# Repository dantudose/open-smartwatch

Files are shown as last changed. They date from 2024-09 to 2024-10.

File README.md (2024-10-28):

# Open-Smartwatch
An open hardware and software smartwatch.

## Main Hardware Diagram

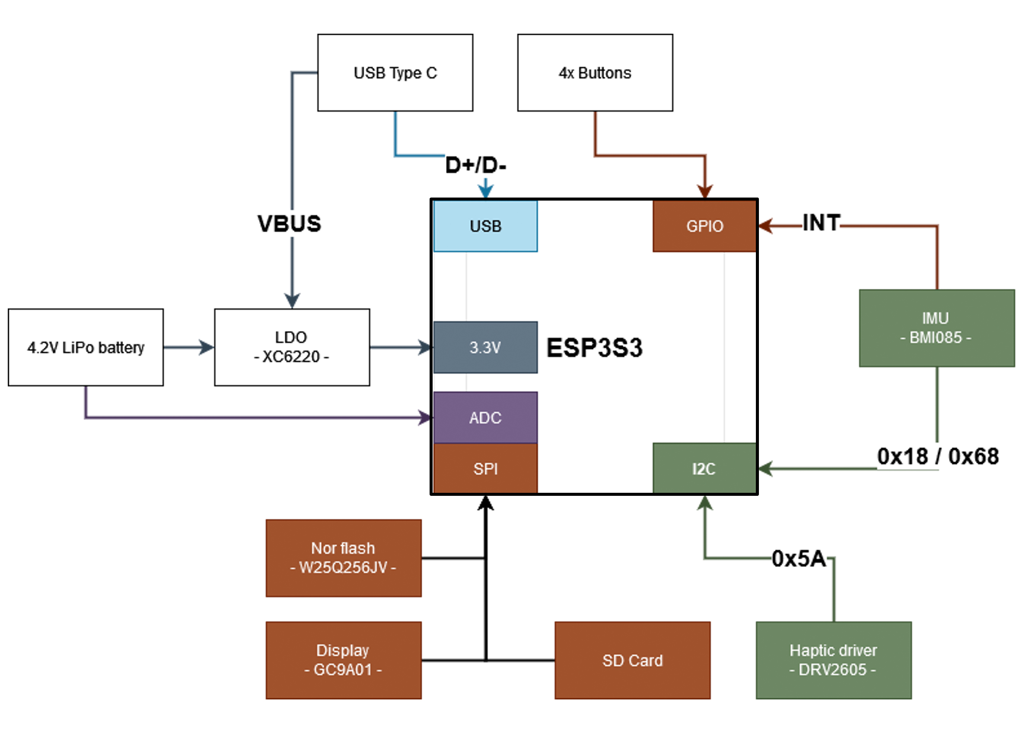
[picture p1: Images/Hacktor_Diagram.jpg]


This is a open-hardware wearable based on the ESP32 microcontroller. It is fully Arduino-compatible and it comes with the following features:
* ESP32-S3 Mini module (240MHz, WiFI, BLE, 512kB SRAM and 4MB Flash)
* GC9A01 1.28 inch color LCD, 240 x 240 pixels
* BMI085 6-axis inertial sensor (accelerometer and gyroscope)
* W25Q256JVEIQ 32MB external SPI Flash
* DRV2605 haptic driver
* SPI card reader
* 200mAh LiPo battery
* USB-C connector

## Repository Contents

* **/Hardware** - Eagle design files (.brd, .sch)
* **/Images** - Board images
* **/Mechanical** - Mechanical files for the case (.stl)
  
### Button Layout

 <div style='float:left'>
<table>
<thead>
  <tr>
    <th>Button</th>
    <th>ESP32 Pin</th>
  </tr></thead>
  <tbody>
  <tr>
    <td>UP</td>
    <td>IO11</td>
  </tr>
  <tr>
    <td>DOWN</td>
    <td>IO26</td>
  </tr>
  <tr>
    <td>BOOT</td>
    <td>IO0</td>
  </tr>
  <tr>
    <td>RESET</td>
    <td>EN</td>
  </tr>
  </tbody>
</table>
 </div>
<div style='float:right'>
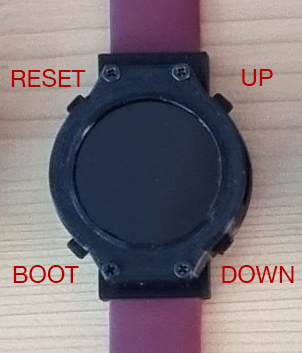
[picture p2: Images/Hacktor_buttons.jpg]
   
  </div>

## Mechanical Dimensions

The watch has the overall dimensions of 43.5 x 48 x 18mm and supports standard 20mm straps.

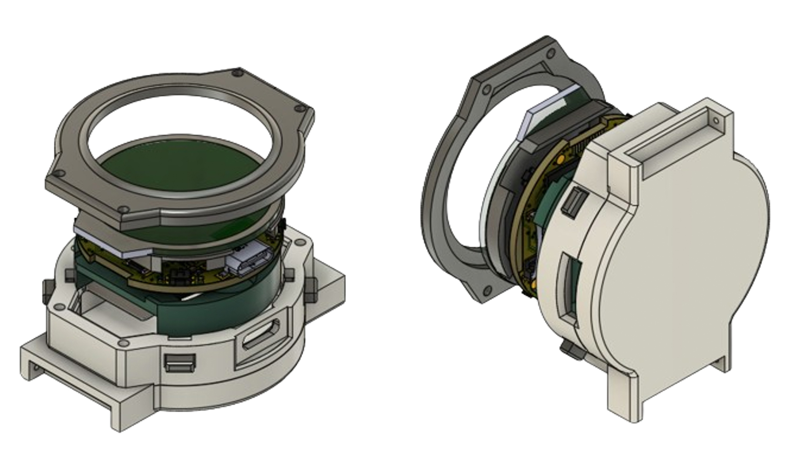
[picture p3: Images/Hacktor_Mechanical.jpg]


## PCB Design

Two-layer PCB design.

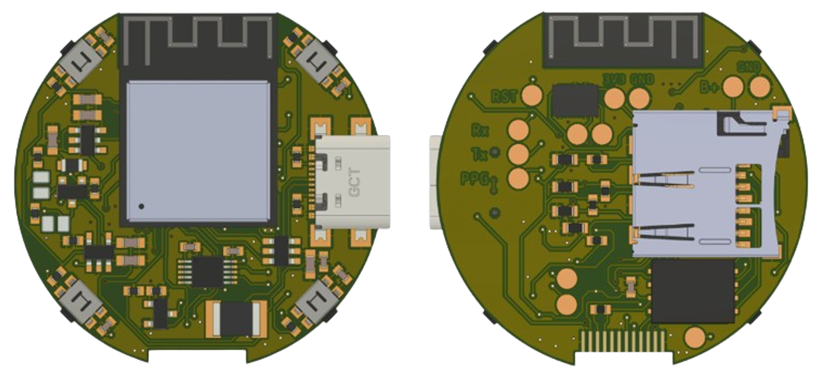
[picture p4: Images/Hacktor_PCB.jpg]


## License Information

This product is _**open source**_! 

Please review the LICENSE file for license information.

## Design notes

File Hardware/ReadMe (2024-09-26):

Eagle CAD files for the schematic and board.

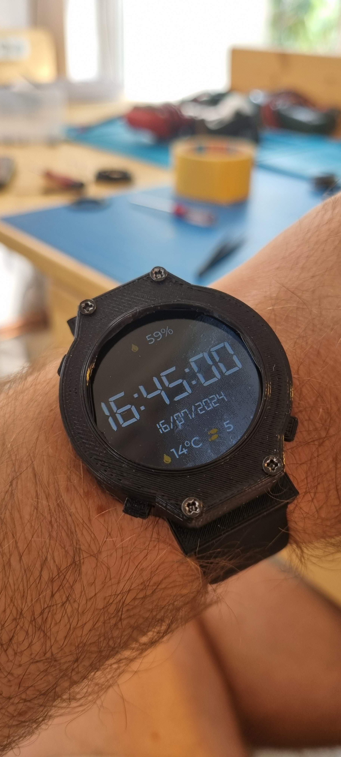
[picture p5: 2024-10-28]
Images/Hacktor_Watch.jpg

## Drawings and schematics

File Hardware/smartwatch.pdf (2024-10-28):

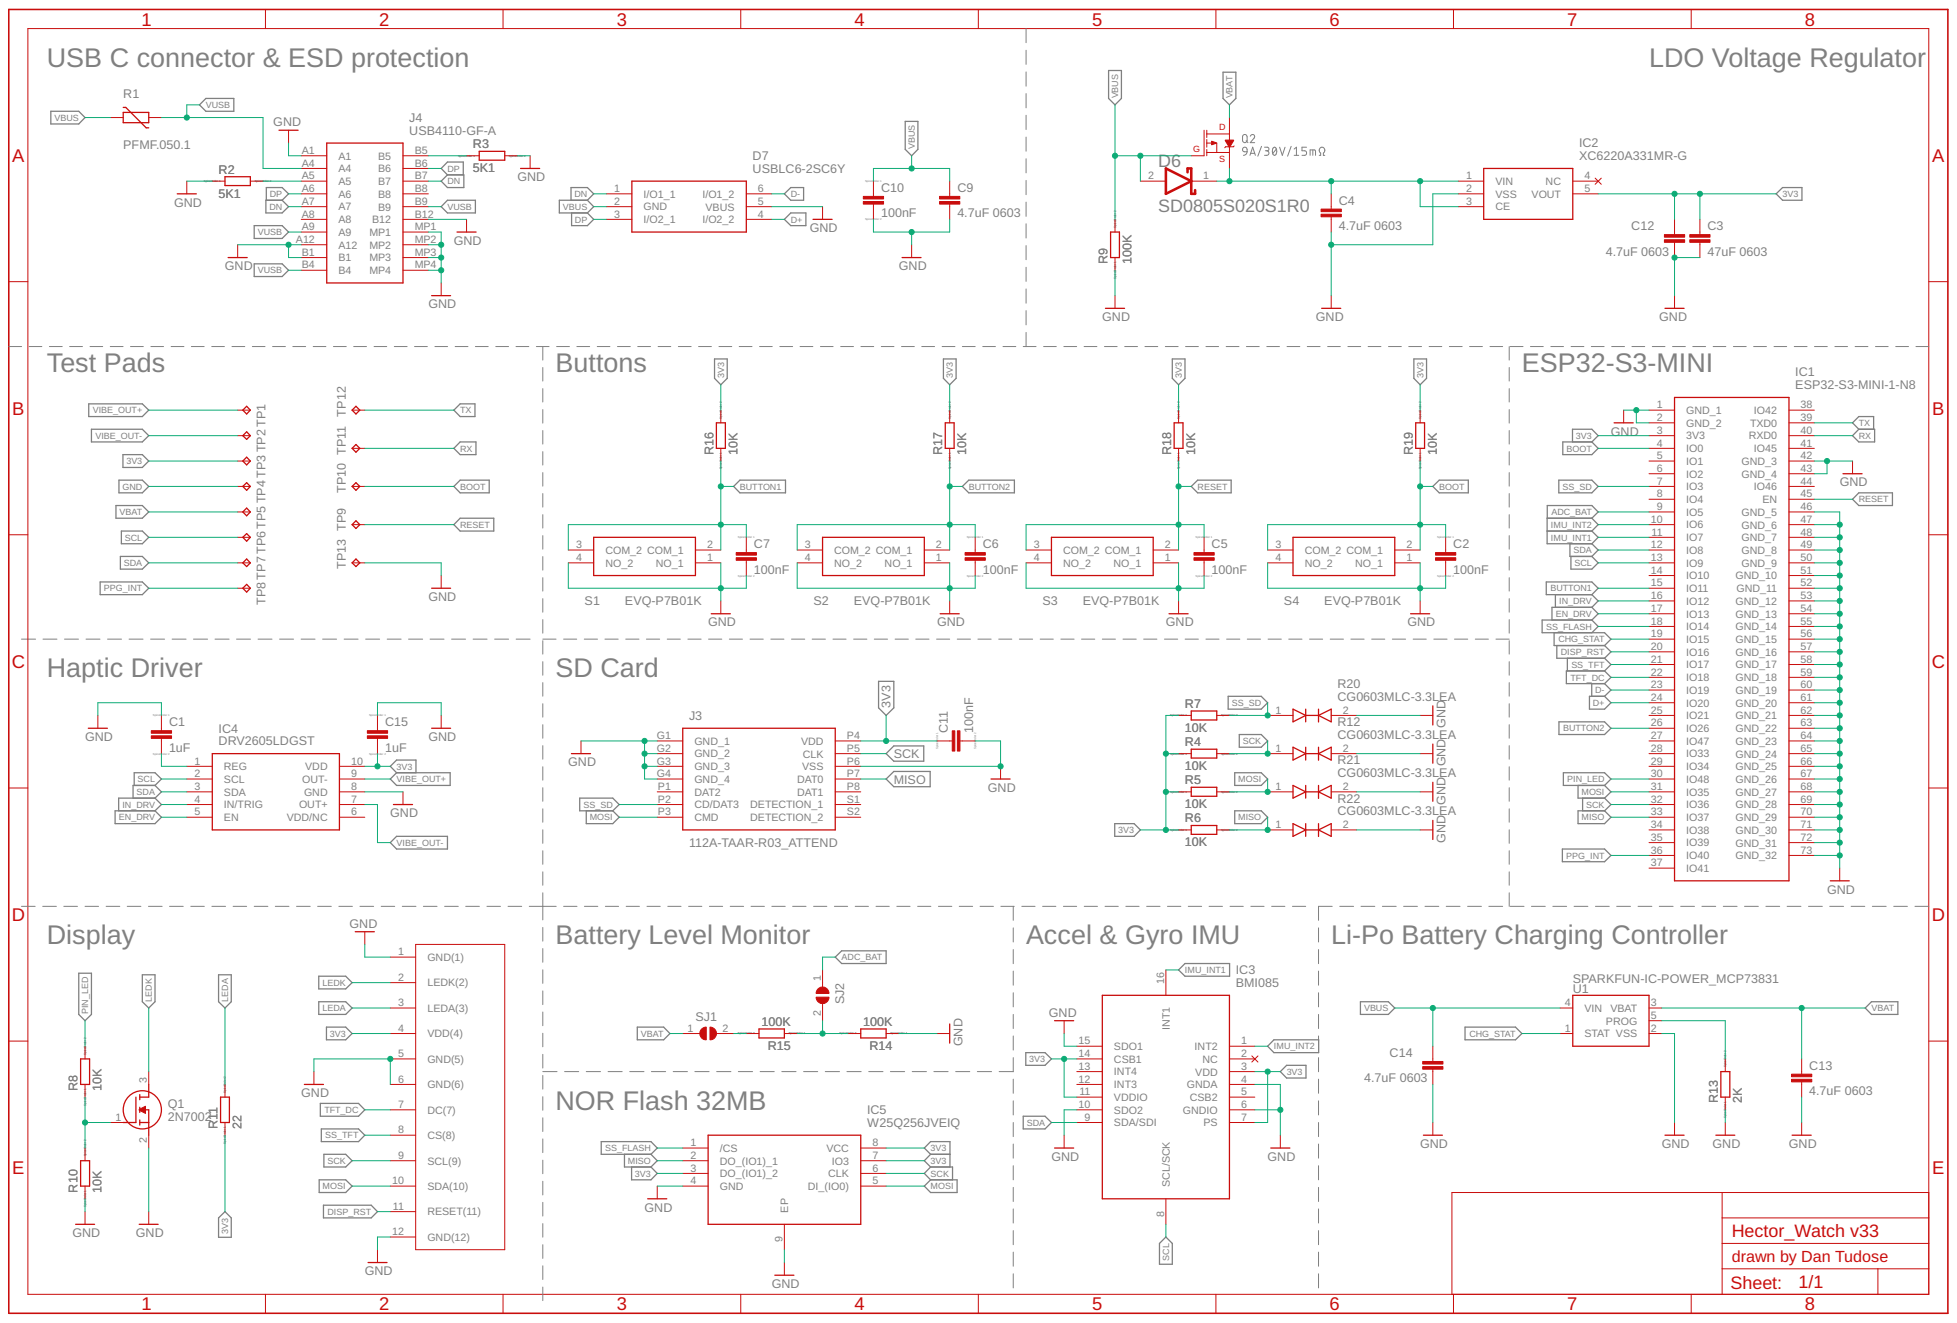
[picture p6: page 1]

USB C connector & ESD protection

SpiceOrder 1 SpiceOrder 2

GND GND

SpiceOrder 1 SpiceOrder 2 SpiceOrder 1 SpiceOrder 2 SpiceOrder 1

SpiceOrder 1 SpiceOrder 2 SpiceOrder 1 SpiceOrder 2

4 GNDIO 5 GNDA 6

drawn by Dan Tudose Hector_Watch v33

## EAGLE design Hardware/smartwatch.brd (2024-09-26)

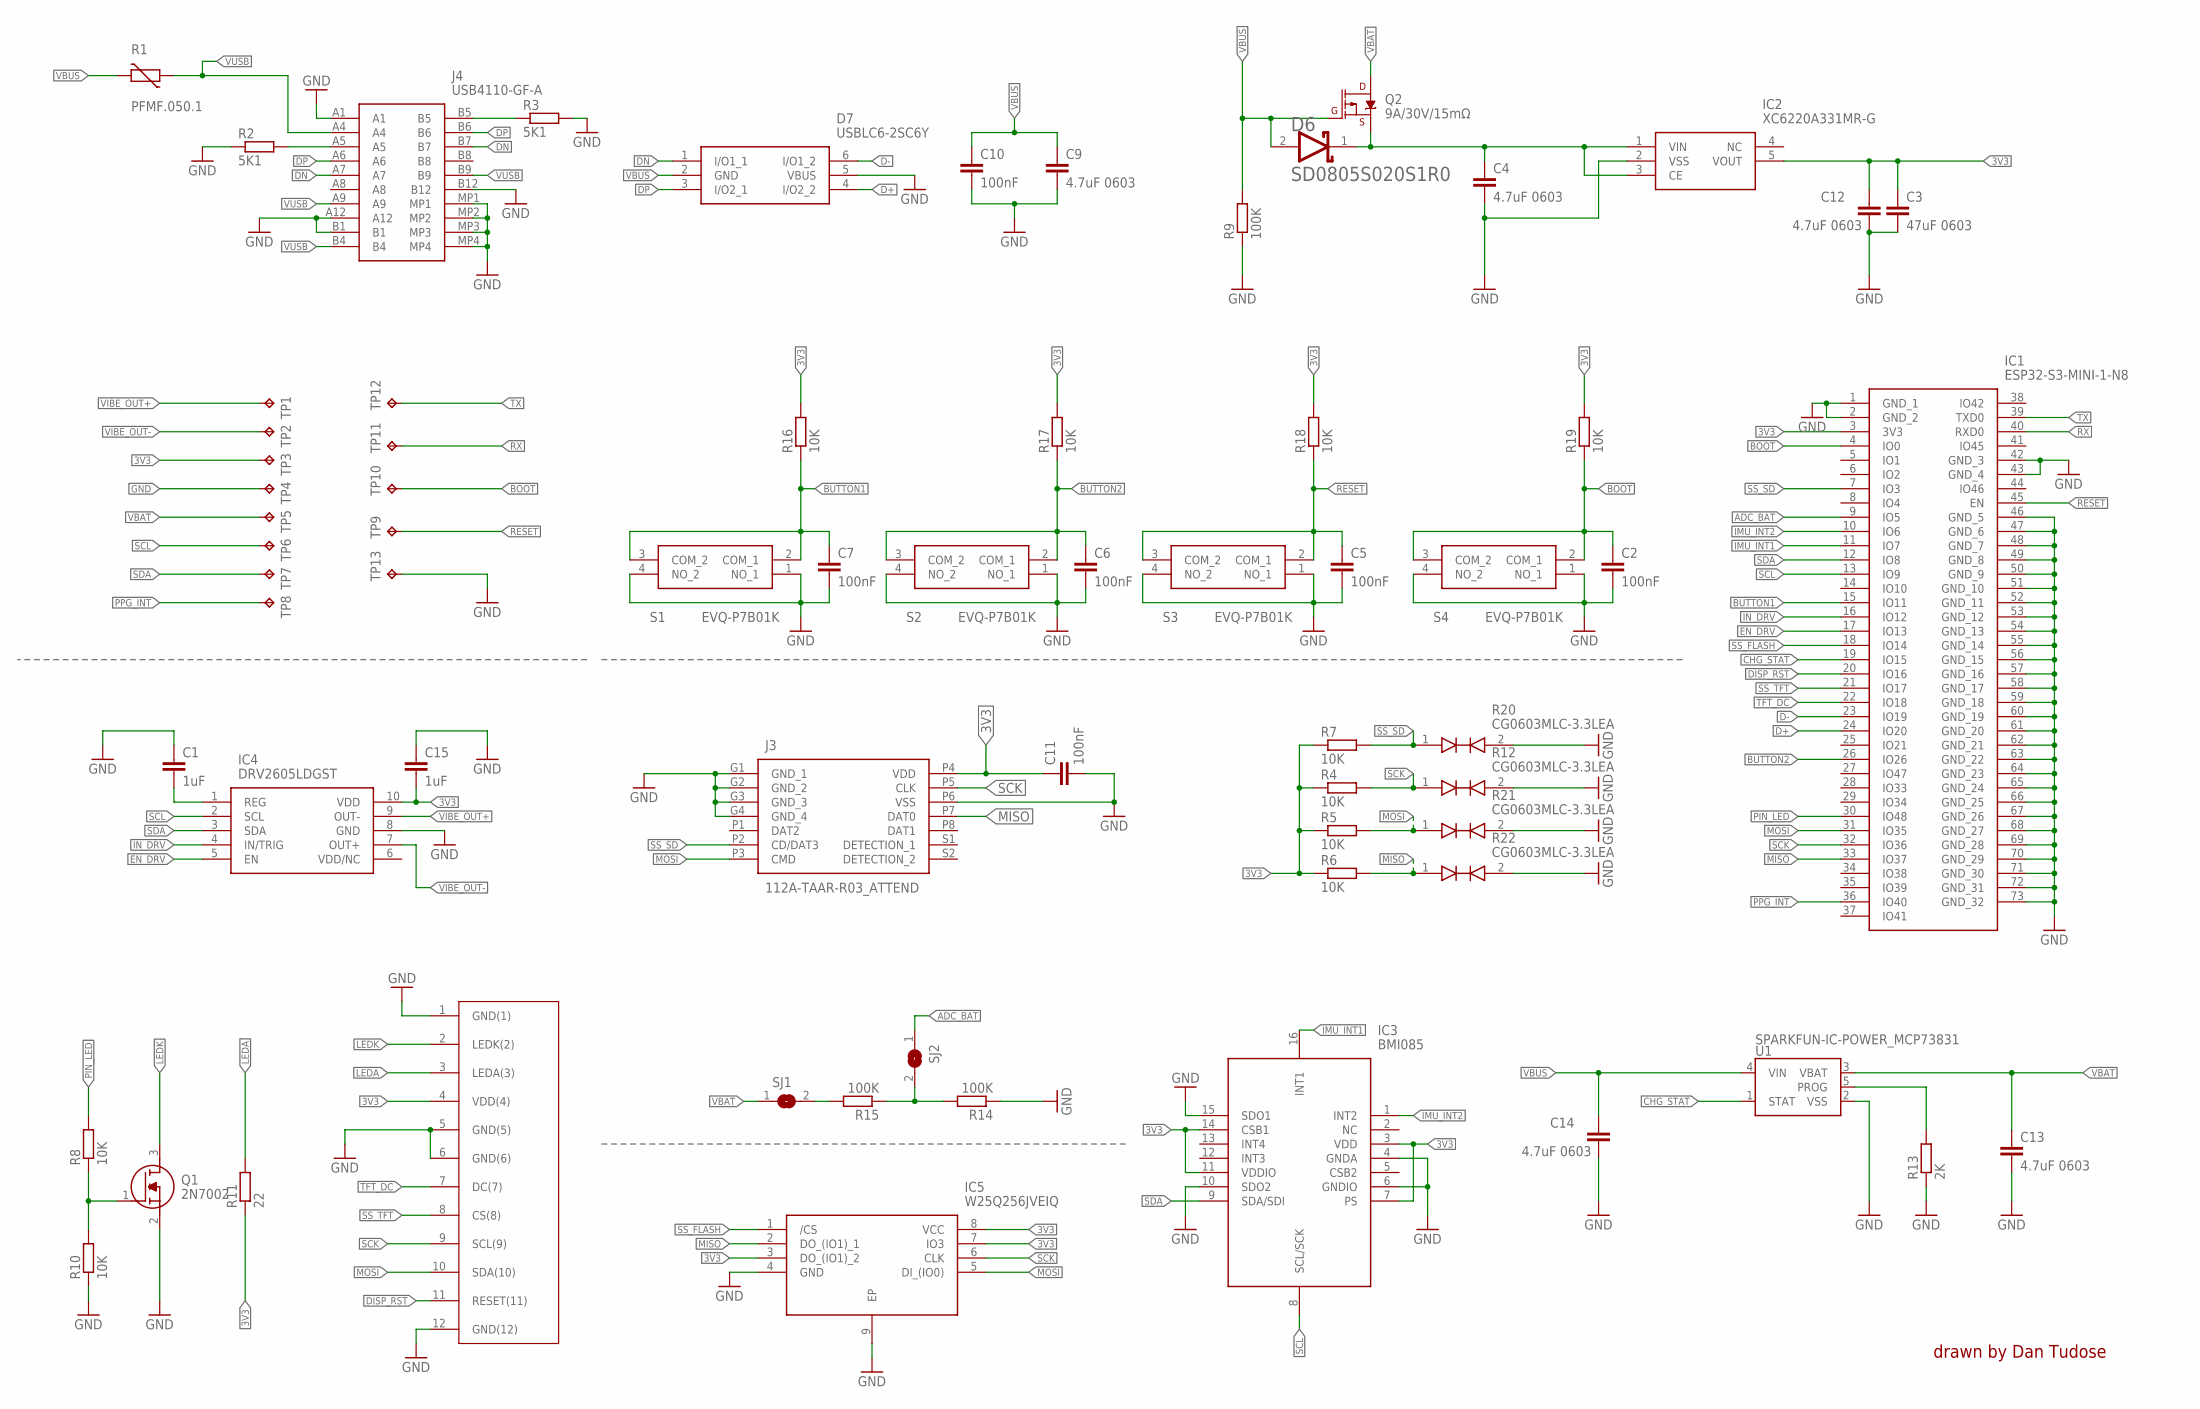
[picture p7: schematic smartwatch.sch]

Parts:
C1, C15: 1uF; EAGLE-LTSPICE_C0402
C2, C5, C6, C7, C10, C11: 100nF; EAGLE-LTSPICE_C0402
C3: 47uF 0603; RCL_C0603
C4, C9, C12, C13, C14: 4.7uF 0603; RCL_C0603
CON1: LCD_FPC
D6: AVX---SD0805S020S1R0_AVX_SD0805S020S1R0AVX_SD0805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; AVX---SD0805S020S1R0_AVX_SD0805S020S1R0_0
D7: USBLC6-2SC6Y; SOT95P280X145-6N
IC1: ESP32-S3-MINI-1-N8; ESP32S3MINI1N8
IC2: XC6220A331MR-G; SOT95P280X120-5N
IC3: BMI085
IC4: DRV2605LDGST; SOP50P490X110-10N
IC5: W25Q256JVEIQ; SON127P800X600X80-9N
J3: 112A-TAAR-R03_ATTEND; 112ATAARR03ATTEND
J4: USB4110-GF-A; USB4110GFA
Q1: 2N7002; SOT96P240X120-3N
Q2: 9A/30V/15mΩ; SPARKFUN-DISCRETESEMI_SOT23-3
R1: PFMF.050.1; VARISTOR_CT/CN1812
R2, R3: 5K1; EAGLE-LTSPICE_R0402
R4, R5, R6, R7, R8, R10, R16, R17, R18, R19: 10K; EAGLE-LTSPICE_R0402
R9, R14, R15: 100K; EAGLE-LTSPICE_R0402
R11: 22; EAGLE-LTSPICE_R0402
R12, R20, R21, R22: CG0603MLC-3.3LEA; DIONC1608X61N
R13: 2K; EAGLE-LTSPICE_R0402
S1, S2, S3, S4: EVQ-P7B01K; EVQP7B01K
SJ1, SJ2: SJ
TP1, TP2, TP3, TP4, TP5, TP6, TP7, TP8, TP9, TP10, TP11, TP12, TP13: TPTP20R; TP20R
U1: SPARKFUN-IC-POWER_MCP73831; SPARKFUN-IC-POWER_SOT23-5

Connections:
3V3: C3.1, C11.1, C12.1, C15.2, CON1.4 (VDD(4)), IC1.3 (3V3), IC2.5 (VOUT), IC3.3 (VDD), IC3.7 (PS), IC3.11 (VDDIO), IC3.14 (CSB1), IC4.10 (VDD), IC5.3 (DO_(IO1)_2), IC5.7 (IO3), IC5.8 (VCC), J3.P4 (VDD), R4.1, R5.1, R6.1, R7.1, R11.1, R16.2, R17.2, R18.2, R19.2, TP3.TP
ADC_BAT: IC1.9 (IO5), SJ2.1
BOOT: C2.1, IC1.4 (IO0), R19.1, S4.2 (COM_1), S4.3 (COM_2), TP10.TP
BUTTON1: C7.1, IC1.15 (IO11), R16.1, S1.2 (COM_1), S1.3 (COM_2)
BUTTON2: C6.1, IC1.26 (IO26), R17.1, S2.2 (COM_1), S2.3 (COM_2)
CHG_STAT: IC1.19 (IO15), U1.1 (STAT)
D+: D7.4 (I/O2_2), IC1.24 (IO20)
D-: D7.6 (I/O1_2), IC1.23 (IO19)
DISP_RST: CON1.11 (RESET(11)), IC1.20 (IO16)
DN: D7.1 (I/O1_1), J4.A7, J4.B7
DP: D7.3 (I/O2_1), J4.A6, J4.B6
EN_DRV: IC1.17 (IO13), IC4.5 (EN)
GND: C1.1, C2.2, C3.2, C4.2, C5.2, C6.2, C7.2, C9.2, C10.2, C11.2, C12.2, C13.2, C14.2, C15.1, CON1.1 (GND(1)), CON1.5 (GND(5)), CON1.6 (GND(6)), CON1.12 (GND(12)), D7.5 (VBUS), IC1.1 (GND_1), IC1.2 (GND_2), IC1.42 (GND_3), IC1.43 (GND_4), IC1.46 (GND_5), IC1.47 (GND_6), IC1.48 (GND_7), IC1.49 (GND_8), IC1.50 (GND_9), IC1.51 (GND_10), IC1.52 (GND_11), IC1.53 (GND_12), IC1.54 (GND_13), IC1.55 (GND_14), IC1.56 (GND_15), IC1.57 (GND_16), IC1.58 (GND_17), IC1.59 (GND_18), IC1.60 (GND_19), IC1.61 (GND_20), IC1.62 (GND_21), IC1.63 (GND_22), IC1.64 (GND_23), IC1.65 (GND_24), IC1.66 (GND_25), IC1.67 (GND_26), IC1.68 (GND_27), IC1.69 (GND_28), IC1.70 (GND_29), IC1.71 (GND_30), IC1.72 (GND_31), IC1.73 (GND_32), IC2.2 (VSS), IC3.4 (GNDA), IC3.6 (GNDIO), IC3.10 (SDO2), IC3.15 (SDO1), IC4.8 (GND), IC5.4 (GND), IC5.9 (EP), J3.G1 (GND_1), J3.G2 (GND_2), J3.G3 (GND_3), J3.G4 (GND_4), J3.P6 (VSS), J4.A1, J4.A12, J4.B1, J4.B12, J4.MP1, J4.MP2, J4.MP3, J4.MP4, Q1.2 (S), R2.1, R3.2, R9.1, R10.1, R12.2, R13.1, R14.1, R20.2, R21.2, R22.2, S1.1 (NO_1), S1.4 (NO_2), S2.1 (NO_1), S2.4 (NO_2), S3.1 (NO_1), S3.4 (NO_2), S4.1 (NO_1), S4.4 (NO_2), TP4.TP, TP13.TP, U1.2 (VSS)
IMU_INT1: IC1.11 (IO7), IC3.16 (INT1)
IMU_INT2: IC1.10 (IO6), IC3.1 (INT2)
IN_DRV: IC1.16 (IO12), IC4.4 (IN/TRIG)
LEDA: CON1.3 (LEDA(3)), R11.2
LEDK: CON1.2 (LEDK(2)), Q1.3 (D)
MISO: IC1.33 (IO37), IC5.2 (DO_(IO1)_1), J3.P7 (DAT0), R6.2, R22.1
MOSI: CON1.10 (SDA(10)), IC1.31 (IO35), IC5.5 (DI_(IO0)), J3.P3 (CMD), R5.2, R21.1
unnamed: C1.2, IC4.1 (REG)
unnamed: C4.1, D6.1 (CATHODE), IC2.1 (VIN), IC2.3 (CE), Q2.2 (S)
unnamed: J4.A5, R2.2
unnamed: R13.2, U1.5 (PROG)
unnamed: J4.B5, R3.1
unnamed: Q1.1 (G), R8.1, R10.2
unnamed: R14.2, R15.1, SJ2.2
unnamed: R15.2, SJ1.2
PIN_LED: IC1.30 (IO48), R8.2
PPG_INT: IC1.36 (IO40), TP8.TP
RESET: C5.1, IC1.45 (EN), R18.1, S3.2 (COM_1), S3.3 (COM_2), TP9.TP
RX: IC1.40 (RXD0), TP11.TP
SCK: CON1.9 (SCL(9)), IC1.32 (IO36), IC5.6 (CLK), J3.P5 (CLK), R4.2, R12.1
SCL: IC1.13 (IO9), IC3.8 (SCL/SCK), IC4.2 (SCL), TP6.TP
SDA: IC1.12 (IO8), IC3.9 (SDA/SDI), IC4.3 (SDA), TP7.TP
SS_FLASH: IC1.18 (IO14), IC5.1 (/CS)
SS_SD: IC1.7 (IO3), J3.P2 (CD/DAT3), R7.2, R20.1
SS_TFT: CON1.8 (CS(8)), IC1.21 (IO17)
TFT_DC: CON1.7 (DC(7)), IC1.22 (IO18)
TX: IC1.39 (TXD0), TP12.TP
VBAT: C13.1, Q2.3 (D), SJ1.1, TP5.TP, U1.3 (VBAT)
VBUS: C9.1, C10.1, C14.1, D6.2 (ANODE), D7.2 (GND), Q2.1 (G), R1.2, R9.2, U1.4 (VIN)
VIBE_OUT+: IC4.9 (OUT-), TP1.TP
VIBE_OUT-: IC4.7 (OUT+), TP2.TP
VUSB: J4.A4, J4.A9, J4.B4, J4.B9, R1.1

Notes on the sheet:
drawn by Dan Tudose

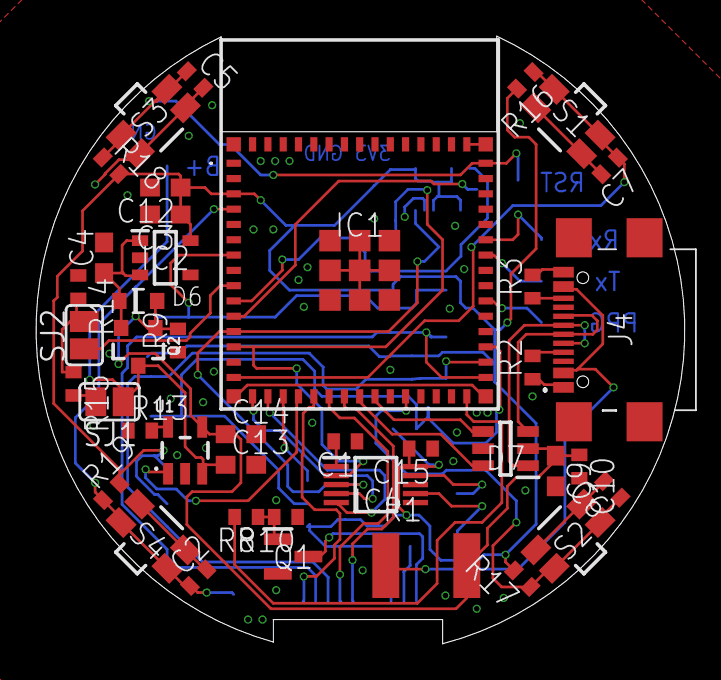
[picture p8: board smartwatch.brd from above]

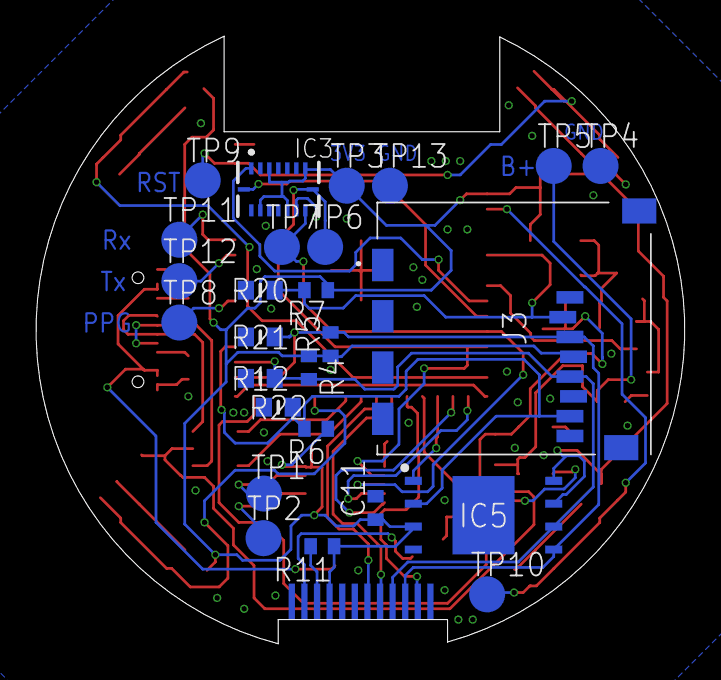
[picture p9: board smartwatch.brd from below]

Board: 2 copper layers, 36.0 x 33.8 mm, 68 parts (27 on the bottom side), 45 nets.
